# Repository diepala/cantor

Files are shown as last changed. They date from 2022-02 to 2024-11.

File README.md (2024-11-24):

# Cantor Keyboard
The Cantor keyboard is a 42 key diodeless split keyboard, designed with simplicity in mind. It is inspired on the popular [corne](https://github.com/foostan/crkbd), [ferris](https://github.com/pierrechevalier83/ferris) and [sweep](https://github.com/davidphilipbarr/Sweep) keyboards, aiming to provide a more ergonomic (stronger column stagger) corne-like layout with a simple, easy to assemble and cheap design.

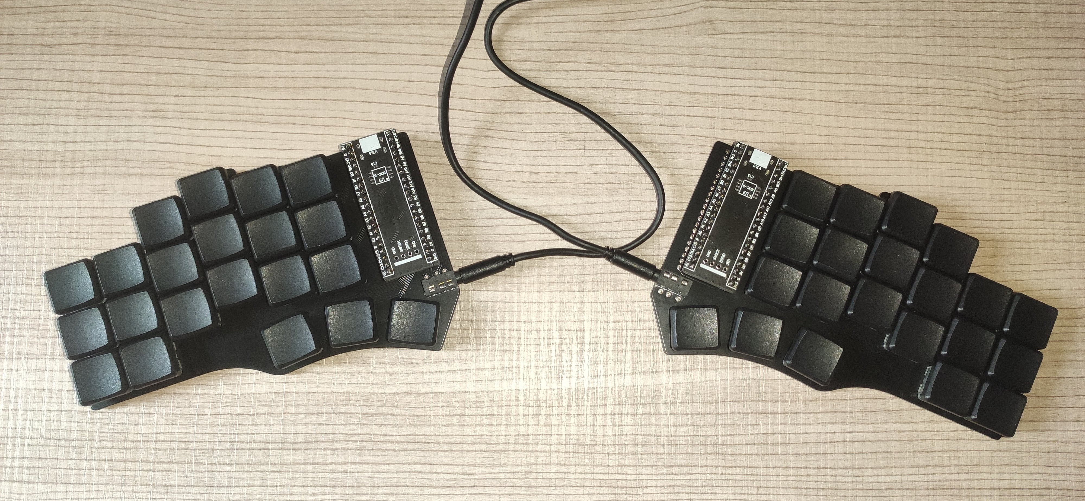
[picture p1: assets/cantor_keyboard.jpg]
Cantor Keyboard


There are two versions of the Cantor:

The **Cantor Classic** uses choc switches with choc spacing. Therefore, only MBK keycaps can be used.

The **Cantor MX** uses either choc V1, choc V2, or MX switches with the slightly larger MX spacing. Keycaps for MX stems can be used. (OEM/SA/XDM/Cherry, etc.) 

Cantor Keyboard

### Why diodeless?

A diodeless design reduces the keyboard assembly time, as the amount of components to solder is significantly reduced.
Moreover, soldering diodes can cause trouble during the keyboard build. Diodes need to be placed in the correct direction, if not, the keys won't work well!
Eliminating diodes will prevent many errors during the assembly process.

## Disclaimers

All the designs and files are provided "AS IS" without any warranty or support.

## Design philosophy

The Cantor is designed with the following goals:

- Comfort
- Powerful
- Low cost
- Simplicity
- Ease of build
- USB-C
- No diodes

The PCB is reversible to reduce manufacturing costs.

## Getting started

Would you like to build this keyboard? Then continue reading!

You can also buy a kit to build the Cantor keyboard from one of the **honorable sponsors**:



<br><br><br><br>
  
### Bill of Materials

To build the keyboard, you will need the following materials:
#### Cantor Classic:
- 2x PCB boards (both are equal since they are reversible)
- 2x STM32F401CC blackpill microcontrollers (they are cheap on aliexpress)
- Pins and sockets for the microcontrollers (blackpill needs 20 pin stripes)
- 42 Choc v1 switches
- 42 MBK keycaps
- Some little rubber feet/bumpers (recommended 6 mm of diameter)
- 2x TRRS jacks (PJ-320A)
- 1x TRRS cable
- 1x USB cable compatible with your computer and the blackpill

#### Cantor MX
- Same as the classic, but switches can be choc v1, choc v2, MX 5 pin, or MX 3pin, and the compatible keycaps for chosen switches. MX 5 pin are preferable to 3 pin because they have more points of contact with the PCB.

- Cantor MX has slots for optional 'Tenting pucks'. They can be [purchased](https://splitkb.com/products/tenting-puck) or [3d printed](https://www.printables.com/model/235433-tenting-puck-for-keyboard-tripod-mount).

### Order the PCB

Download the gerber file from releases, and submit it to your favorite PCB manufacturer. The keyboard designs have been tested with JLCPCB. More details on the ordering process can be found in the [PCB Ordering Guide](doc/pcb_ordering_guide.md).

Note: if you don't want a random tracking number to be printed in the PCB, make sure to select the option 'Remove Order Number' in JLCPCB.

### How to Build

To build the keyboard, you'll also need a soldering iron and some tin. Follow the [build guide](doc/build_guide.md).

### Firmware

The Cantor keyboard uses the QMK firmware, which already supports this keyboard.

To flash the firmware to the microcontroller connect the blackpill to your computer and set it to bootloader mode. To do this the first time:

1. Press and hold the BOOT0 button.
2. Press and release the NRST button.
3. Release the BOOT0 button.

The following times you want to flash the keyboard, it is much simpler thanks to bootmagic. Hold the top left key of the keyboard and plug the microcontroller. If flashing the right part, hold the top right key.

## Feedback

If you have build this keyboard, please fill [this form](https://forms.gle/nfJCsei5hyHbjaHn9) to provide feedback. This will help to improve the keyboard design in future revisions.

Also, you can open an issue reporting any problem or feature request.

## Support

The development of a keyboard takes time and money. If you like this keyboard a want to support me for the work and to develop future revisions of the keyboard, consider donating:

PayPal: 
GitHub: [Here](https://github.com/sponsors/diepala)

### Honorable sponsors

Thank you very much to everyone contributing and/or sponsoring this project. Special thanks to the honorable sponsors:




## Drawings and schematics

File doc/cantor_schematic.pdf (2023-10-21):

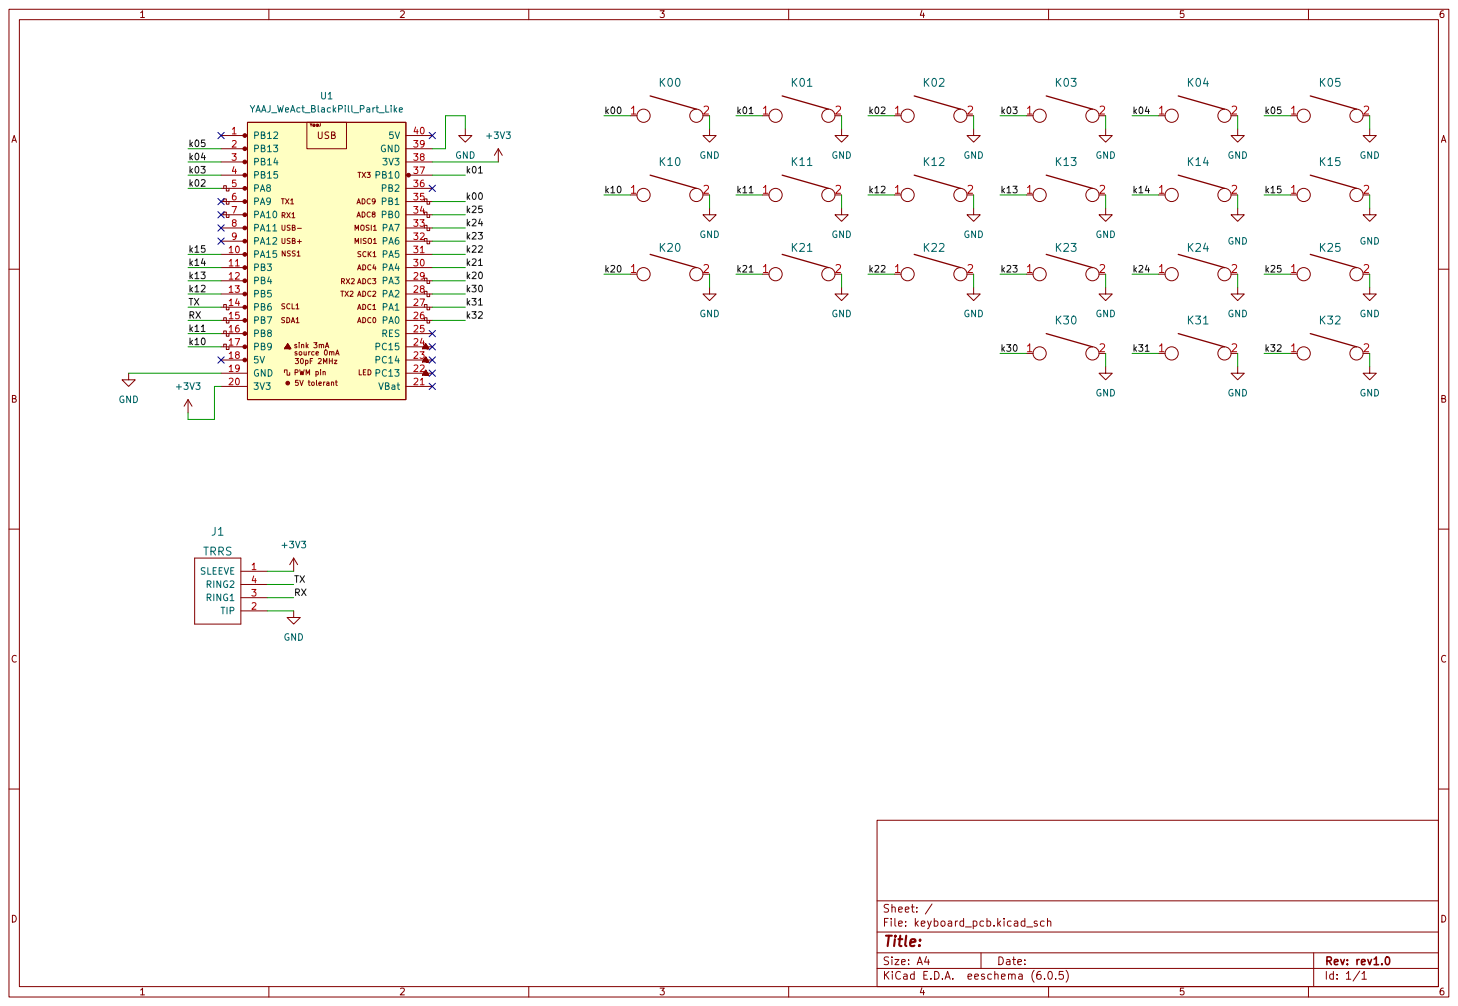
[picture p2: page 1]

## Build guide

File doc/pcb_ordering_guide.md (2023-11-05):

# PCB Ordering Guide.
How to order this board from a PCB vendor - helpful info if it's your first time ordering a PCB.

Most PCB vendors have a similar ordering process. I use [JLCPCB](https://jlcpcb.com/) because they are usually the most cost effective. I've had good luck with [Elecrow](https://www.elecrow.com/) too. [You can find PCB price comparison tools online.](https://pcbshopper.com/) When comparing pricing, the board dimensions are  143mm x 93mm. (Usually anything under 100x100mm is really cheap - so be sure to use the 143x93 dimensions when pricing).

Usually the minimum quantity to order is 5 boards. 

The production files are known as "gerbers", and they are usually uploaded as a `.zip` file. (It's essentially a collection of files for each layer of the board, like holes, graphics, traces etc.) 

In this repo, the gerber file for the Cantor classic and the Cantor MX can be found under [releases](https://github.com/diepala/cantor/releases).

The homepage of JLCPCB has a drag & drop upload. Drag the gerber `.zip` and drop it on the "add gerber file" box.
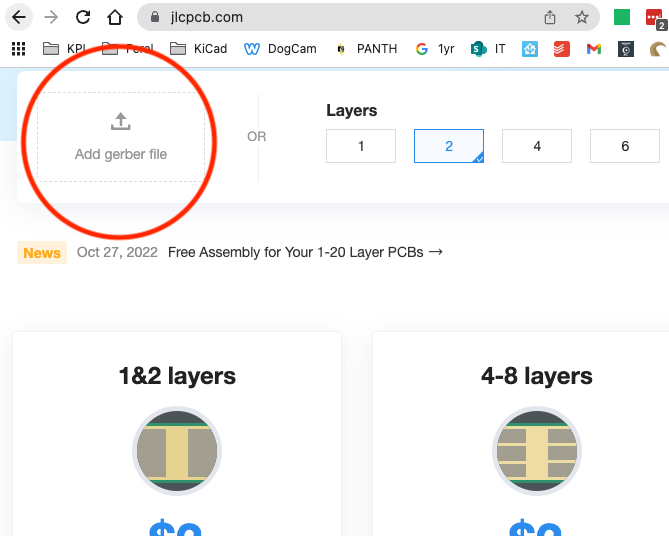
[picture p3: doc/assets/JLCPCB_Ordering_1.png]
JLCPCB Home


While the file is uploading, it will take you to an options screen. Once the board size is detected<sup>1</sup>, the price<sup>3</sup> will update accordingly.
Changing the pcb color<sup>2</sup> may impact production time and price.
Shipping estimates<sup>4</sup> can vary widely, so be sure to check those. (You'll see these options again during checkout).
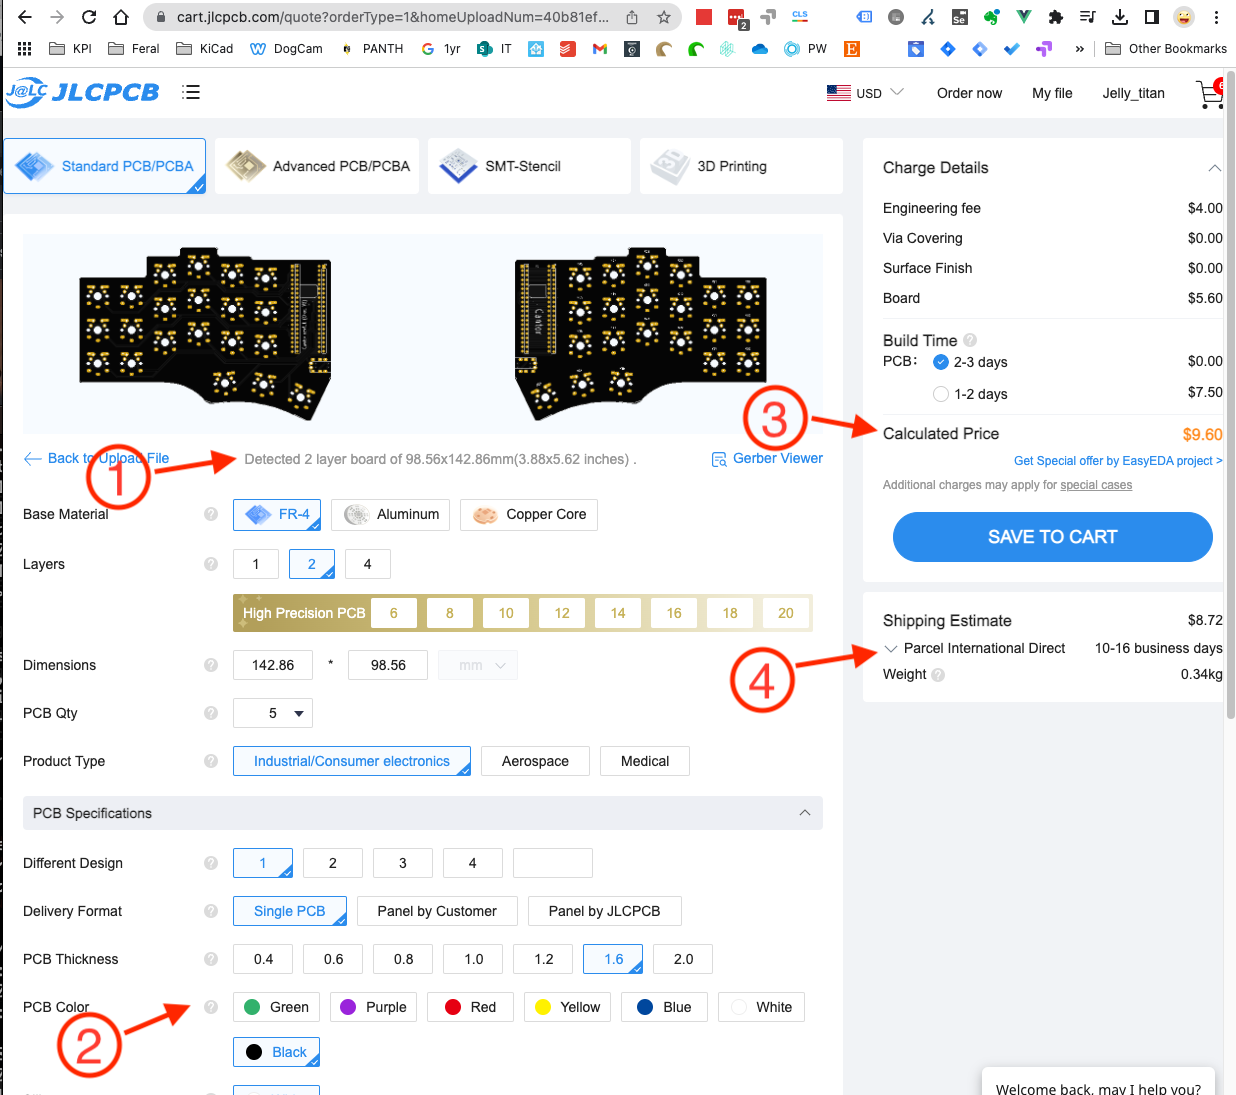
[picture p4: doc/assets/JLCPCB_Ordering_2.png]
JLCPCB Home

It's worth noting, the default pcb surface finish contains Lead. For boards in cases, this is usually not a problem. If you're going to rock a naked board, consider going with "lead free" for a few bucks more.

JLCPCB Home
The remainder of the checkout process is standard ecommerce stuff. After you pay for your order, it will be reviewed before going into production. They will let you know if the file has any issues.

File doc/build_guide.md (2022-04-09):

# Build Guide

1. Solder the pin headers to the blackpill microcontrollers. The microcontroller must be face down, as shown.

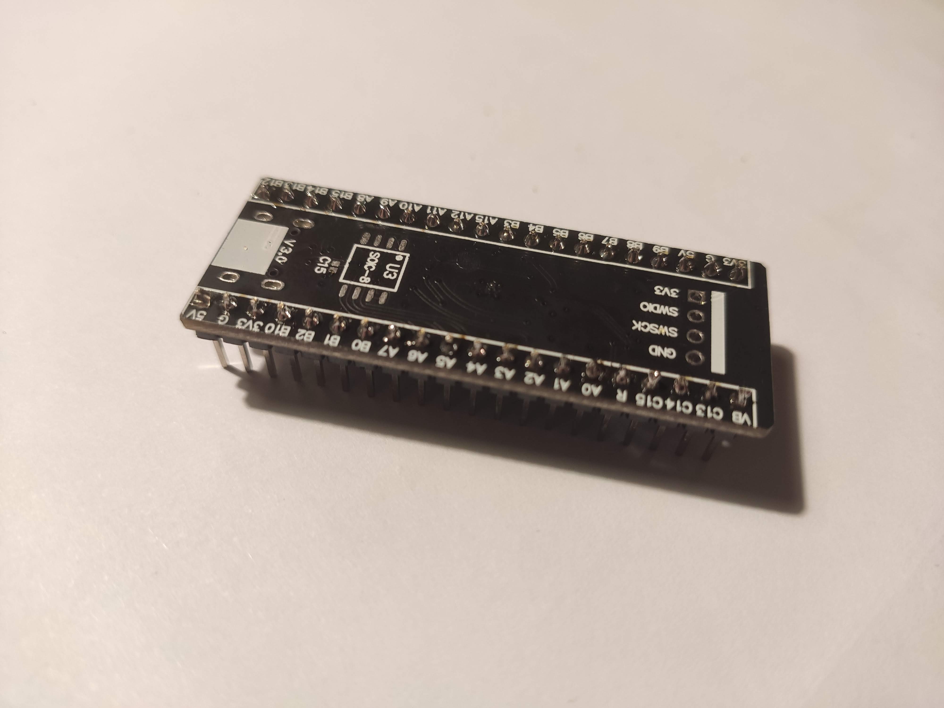
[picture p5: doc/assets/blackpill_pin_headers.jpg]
blackpill with pin headers
   

Optionally, flash the firmware onto the microcontroller to ensure it is not defective.

2. Solder the blackpill sockets and TRRS jacks on both PCBs, as shown. Sockets must be placed on top of the white PCB markings. ALthough using sockets is not strictly necessary, it will make it easier to replace the blackpills in case they die for any reason. Also, make sure you solder the components on different sides of the PCBs, so you end up with a right and left side and not two sides of the same hand.

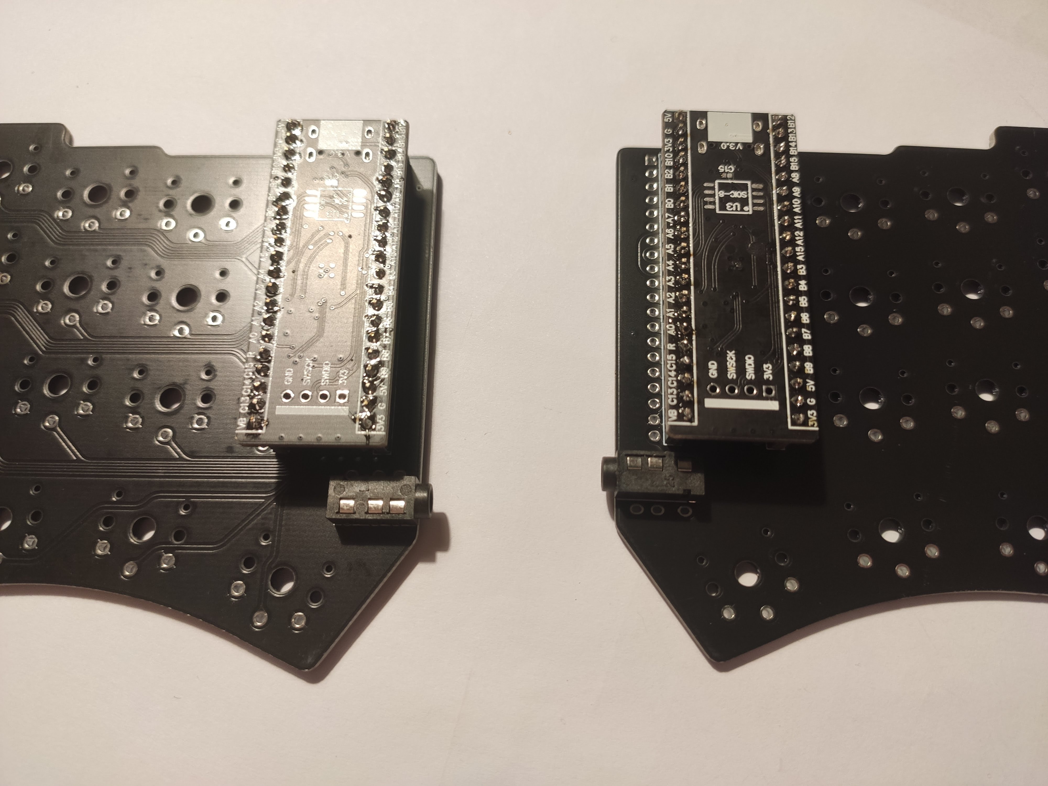
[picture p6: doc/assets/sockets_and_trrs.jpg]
sockets and jack
   

3. Place and solder the switches.

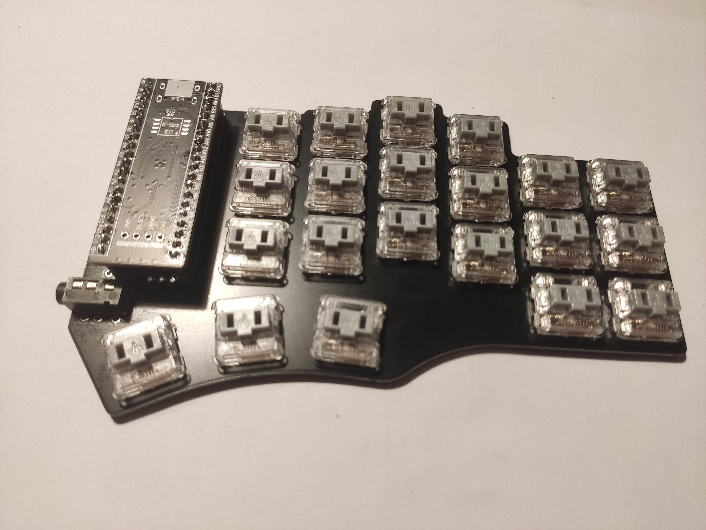
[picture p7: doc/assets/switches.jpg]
switches
   

4. Place the rubber feet on the bottom of the PCB.

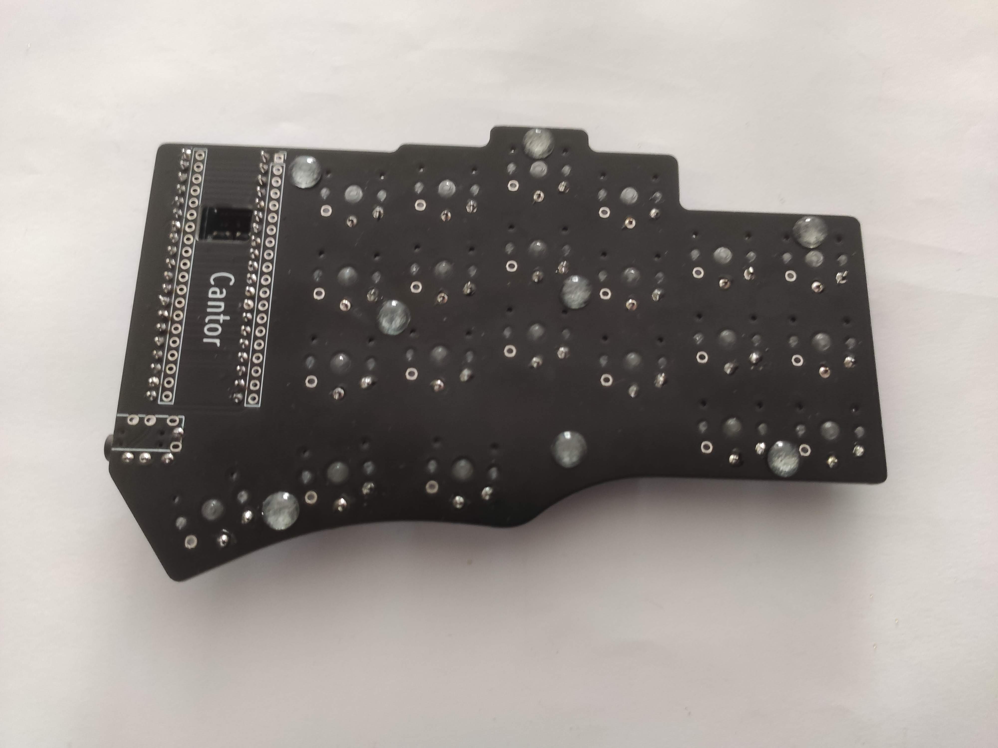
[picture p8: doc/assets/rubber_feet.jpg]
rubber feet
   

5. Place the keycaps on top of the switches. Congrats! Your keyboard is built!

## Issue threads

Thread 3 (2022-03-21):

Add Cantor to splitKbCompare

azzamsa, 2022-03-21:
Hi.

Would you like to  add this to https://github.com/jhelvy/splitKbCompare :)

Would like to compare to other keyboard. Especially [Torn](https://github.com/rtitmuss/torn).

diepala, 2022-03-21:
I will take a look on how to do it when I have time. Meanwhile, you can see how the switches are layed out with kiCad.

azzamsa, 2022-05-23:
Related: https://github.com/jhelvy/splitKbCompare/issues/84

azzamsa, 2022-05-26:
In case anyone want to print the layout (without installing the KiCad):

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

[cantor.pdf](https://github.com/diepala/cantor/files/8779709/cantor.pdf)

l4u, 2022-06-27:
It's available at splitKbCompare now.

azzamsa, 2022-10-24:
> It's available at splitKbCompare now.

Thank you!

Closed 2022-10-24.

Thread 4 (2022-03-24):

Release a 36 key Cantor version

fourstepper, 2022-03-24:
Hi!

A 36 key version of this would be great, are you planning on making this revision?

diepala, 2022-03-25:
Yes, a 36 key version will be the next variant of the Cantor keyboard. I am waiting to having more feedback on the current version first.

stuart-warren, 2022-06-09:
Supporting the nice!nano would be amazing with fewer keys

stuecklberger, 2022-07-20:
FYI: In the meantime someone already created a 36 key version of the Cantor and called it Cantor Remix:

https://github.com/nilokr/cantor-remix

Lumi317, 2022-10-21:
Maybe you would be interested in the Sweep?
https://github.com/davidphilipbarr/Sweep

diepala, 2024-01-05:
Fixed by #25

Closed 2024-01-05.

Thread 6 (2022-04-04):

Create a MX compatible version

twalker, 2022-04-04:
It'd be fantastic to have a version of Cantor that was compatible with MX switches.

MX compatible hot swap sockets would be ideal IMHO, they:
* Are easier to solder than switches themselves
* Allows exploring different switches

twalker, 2022-04-07:
> Have you tested or seen other plateless keyboards with the configuration you propose?

No, I have not. All the MX compatible keyboards I've built (Corne, Kyria, Sofle, etc) used a base and switch plate. They're quite stable with a case, but I imagine they'd be less stable with one. I'm naively imagining a different version of the PCB with the same layout, with non-choc key spacing, along with a switch and base plate designs. If that conflicts with the goals (low cost) of the Cantor, or is impractical, then I totally understand.

diepala, 2022-04-09:
I don't want a switch plate to be mandatory for the build. The MX keyboard won't be a priority for now, but in the future we could make some tests for MX switches.

twalker, 2022-04-09:
@diepala , I look forward to any future possibile explorations of an MX version. As a software engineer, I'm not very skilled with electronics or PCB design, but would happy to be a tester if/when one is needed. Thank you.

ratsclub, 2022-06-24:
Hmm, I just stumbled upon this issue. I can't really build this keyboard for an affordable price because of its switch... There are some MX compatible switches from Red Dragon that are **really** affordable tho. So I'd be happy to try the MX model if it happens to come out!

taurhine, 2022-08-17:
This is a great improvement over corne design. It would be awesome to have it with MX switches!

artsbentley, 2022-09-14:
Yes would love an MX design!

diepala, 2022-09-16:
Seeing that many people would like this version, I will probably make an MX version.

fabikroeger, 2023-02-14:
An MX design would be awesome :+1:

taurhine, 2023-02-18:
or MX Low Profile :heart_eyes: https://www.cherrymx.de/cherry-mx/mx-low-profile/mx-low-profile-red.html

mejobloggs, 2023-02-27:
Redragon AliExpress has two MX compatible low profile switches... Could be a potentially good option!

https://www.aliexpress.com/item/1005004299855522.html

https://www.aliexpress.com/item/1005003606992057.html

However, I have not used either, so I can't verify if they genuinely are MX compatible

albertothedev, 2023-04-04:
Any progress on this? I really like the improvements made over CRKBD but the use of Choc keys is a dealbreaker for me, like I'm sure it is for many others.

JayceFayne, 2023-12-28:
This issue was fixed by #25

Closed 2024-01-05.

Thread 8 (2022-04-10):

LEDs control

wvffle, 2022-04-10:
Is it possible to control the LEDs of the blackpill?

For example I'd love to completely turn the red LEDs off. Or better yet, turn them on when I'm switching layers.

diepala, 2022-04-12:
As far as I know, it is not possible to turn off the red power led, as this is not controlled by the microcontroller.
However, the blackpill has another LED which can be controlled, that is connected to pin C13. It should be possible to configure this LED with QMK, although not sure if it will be very visible due to its position.

kovasap, 2024-10-14:
@wvffle did you ever end up figuring this out?

wvffle, 2024-10-15:
@kovasap no.

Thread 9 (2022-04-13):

Add support for tenting puck

jbarr21, 2022-04-13:
Would it be possible for you to add support for splitkb's [tenting puck](https://splitkb.com/products/tenting-puck)? This would add to the Comfort aspect of the design philosophy while not hurting the Ease of build since it is optional to use.

diepala, 2022-04-18:
Not sure how the tenting puck is mounted, but I'll investigate to see if it can be added.

diepala, 2023-10-24:
And MX version of the keyboard is coming in #25 and it has holes for the tenting puck.

Closed 2024-01-05.

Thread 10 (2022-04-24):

Wireless technically possible?

kekscode, 2022-04-24:
Hello 👋
Long time corne low profile user here. I recently built a corne with ZMK firmware and nice!nano v2 MCU and don’t want to go back having canbles.

I love your pcb design (especially the stagger) and the diodeless approach. Do you think it is possible build a wireless variant of the cantor?

diepala, 2022-04-28:
You would need a blackpill with bluetooth support, but I don't know if that exists.

kekscode, 2022-04-28:
Maybe not (yet?). I‘ll build a cantor this weekend and if it suits me i will do some research. Kudos for the simple design. I am looking at the pcbs right now and i like the KISS approach a lot 👍

azzamsa, 2022-05-16:
@kekscode any update? I love to have the wireless version too.

kekscode, 2022-05-17:
Not really feasible at the moment.

funkycode, 2023-03-07:
I would assume it is with https://mechwild.com/product/pillbug/
Blackpill compatible with BLE and ZMK support

Closed 2022-04-28.

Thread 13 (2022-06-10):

Pin for determining left/right side

dariogoetz, 2022-06-10:
Is there a pin that is grounded for one of the blackpills and not for the other? It would allow determining if an instance of the firmware runs on the left or right half.

I wrote a keyberon-based firmware for the cantor, where I would like to use such a pin. The firmware can be found here: https://github.com/dariogoetz/cantor-firmware-keyberon

diepala, 2022-06-18:
There is no pin grounded on one side but not in the other. I thought of it when designing the keyboard, but that was incompatible (or at least hard to achieve) with a reversible PCB.

dariogoetz, 2022-06-20:
If I understand the pcb correctly, there are two footprints for the MCU. One is used for the left half and the other for the right one. Is it not possible to ground one pin (e.g. A9) only for the one of the two footprints? Am I missing something?

Closed 2022-06-18.

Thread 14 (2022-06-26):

bigger holes for Mill-Max capabilities

itenatic, 2022-06-26:
Tried to insert some 0305 mill-max sockets to make the cantor hotswappable, but they don't fit. the metal rings for the connections make it a little too tight. maybe in the next iteration of the cantor this can be taken into account

maverick1872, 2022-11-11:
@diepala Any idea on when/if hot swap support may be added?

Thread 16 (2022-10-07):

Only USB-C ports

Lumi317, 2022-10-07:
Would it be possible to create a version of the Cantor whose TRRS ports are replaced by USB-C ports?

diepala, 2022-10-16:
Using USB-C ports was an option I thought about when designing the Cantor, but I discarded it because soldering would be more difficult to do by hand. So it is not going to be implemented.

Lumi317, 2022-10-16:
Thank you for taking the time to answer me and thank you very much for creating and sharing the Cantor. <3

Lumi317, 2022-10-17:
I may be wrong, but I seem to have read that some complicated soldering can be done by machines in factories producing PCBs if they are provided with a PCBA file.
Wouldn't this be a way to take advantage of the solidity and universality of USB-C on the Cantor while avoiding the difficulties of manual soldering?

Closed 2022-10-16.

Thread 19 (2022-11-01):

4 keys not working

usizu, 2022-11-01:
Just built this great keyboard, have an issue with 4 keys not working on the right-side though.

They correspond on the default mapping to the `[`, `n`, `m` and `,` keys. So the top-right key, and the bottom left-three (within the main block).

QMK key tester:
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

I suspect the issue is with the controller, not the switches. If I swap the controller with the one on the other side, then the same mirror-positions stop working on that side.

I'm new to keyboards and hope to get some help in troubleshooting this.

1) Could it be something simple like one or more improperly soldered pins on the controller?
2) Is it easy to determine which pins govern these keys, so I can adjust the soldering on those pins?
3) What would be sufficient criteria to determine if I should just buy a new blackpill?

Thanks for any help.

diepala, 2022-11-19:
Hi, probably you will have to replace blackpill, but you can check if the balckpill is working by short-circuiting to ground, with a wire, the pins corresponding to the non-working keys. Connecting a pin to ground is equivalent to pressing the associated key, so you should see as if that key is pressed in the computer.

Your keys correspond to pins B1, A6, A7 and B0.

usizu, 2022-12-10:
Hi, thanks for this message.
I finally got around to trying this, and indeed the pins from A6 up to B1 don't register a keypress whereas the others do, so this seems to affirm that its this blackpill unit that is faulty, thanks for the help

------- Original Message -------
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

Closed 2023-02-23.

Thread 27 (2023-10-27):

Board always in Bootloader-mode

noggynoggy, 2023-10-27:
I am sorry if this is not the right place to ask this, but I don't know where else to ask:

One half of my Cantor doesn't type. The Blackpill seems to be in bootloader mode constantly, even after flashing. After I disconnect the cable, and replug, I can instantly flash with `qmk`, without having to press the `BOOT0 NRST nrst boot0` combo.

I had to resolder some parts on that side (I'm bad at this), so I suspect it's because of bad soldering somewhere. What pins (or switches?) should I take a look at? What could cause the Blackpill to be in Bootloader mode all the time? I tried to read the Documentation of the board, but I'm afraid all of it went right over my head...

Thanks in advance!

Closed 2023-11-10.

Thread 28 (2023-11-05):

MCU Orientation

fla-t, 2023-11-05:
I have ordered a cantor PCB, and just waiting for the switches to be built. I noticed that you have heavily said that the controller must be face up.

But, in the PCB I noticed that there are 2 Pin arrays, It seems like they are mirror opposite of each other. Meaning I don't need to face down the PCB if I choose the one that has a square white mask around it.

My question is am I right?

Sorry if it doesn't feel like an issue, because I have no other way to ask this.

diepala, 2023-11-05:
As it was originally designed, the microcontroller should be soldered on the white mask face down as shown:

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

But you are right in that it can be soldered face up on the other row of holes.

fla-t, 2023-11-06:
Thank you so much, I think I should update the docs a little bit.

Closed 2023-11-05.

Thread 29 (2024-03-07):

The MX release contains two gerber files.

The-Abe, 2024-03-07:
The zip release for the MX version contains the gerber files and another zip containing gerber files.

This causes jlcpcb to reject the board during review.

Blubberland, 2024-04-08:
Cannot confirm.
The second layout was automatically stripped away when I added it to the cart. (I was wasn't sure how it would be handled during the order process, so I just waited until delivery).
Package was delivered today and contains 5 pieces (not 10).
Would have been nice to know beforehand. I would have ordered an even number. Could be added to the [ordering guide](doc/pcb_ordering_guide.md).

simonvanbernem, 2024-04-26:
I encountered the same thing.

jlcpcb emailed me, asking what to do about the internal zip file, and I instructed them to ignore it (which I hope was the right thing, as it claims to be v1.61 dated 10-24-2023, while the release zip is v1.6 from 11-05-2023 (later date, but earlier version??).

It would be great if the internal zip file could be deleted, so that newbies like me don't get surprised by this.

yantongl, 2024-05-16:
I ran into the same problem.

If you unzip the `gerber-cantor-mx-rev1.6.zip` file, you will see it contains another zip file `cantor_mx_v1.61_10-24-2023.zip`. I am going to tell them to ignore the internal zip file as @simonvanbernem said above.

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

simonvanbernem, 2025-04-24:
> If you unzip the `gerber-cantor-mx-rev1.6.zip` file, you will see it contains another zip file `cantor_mx_v1.61_10-24-2023.zip`. I am going to tell Jlcpcb to ignore the internal zip file as [@simonvanbernem](https://github.com/simonvanbernem) said above.

For the record: This turned out to be the correct choice. Everything worked out in my case.

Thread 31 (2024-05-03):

Request for Adding RGB Lighting to Cantor Keyboard PCB for Enhanced Functionality

ripertio, 2024-05-03:
As a user who built the Cantor Keyboard as my first split keyboard, I have thoroughly enjoyed the experience, especially appreciating the simplicity of the build process and the clear assembly guide provided. Despite being new to the splitboard game, I found the Cantor Keyboard to be user-friendly and intuitive.

One feature that I believe would greatly enhance the Cantor Keyboard is the addition of RGB lighting to the PCB For a beginner like me, having RGB lighting on the Cantor Keyboard would provide visual cues for different functions, such as indicating which layer is currently active.

I believe that integrating RGB lighting into the Cantor Keyboard PCB would not only elevate its overall appeal but also provide practical benefits for users, especially those new to split keyboards. Thank you for your attention to this request.

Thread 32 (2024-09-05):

Keyboard doesn't work until I reconnect it

arielarmijo, 2024-09-05:
The keyboard works fine, I love it, but after I turn on the PC, the  keyboard won't work until I disconnect and re-connect it again.

I have build it with the blackpill [STM32F401CCU6 3.0](https://es.aliexpress.com/item/4001049840288.html). In my config.h file i have this code:
```
#pragma once

#define MASTER_LEFT
#define USB_WAIT_FOR_ENUMERATION
#define LAYER_STATE_8BIT
```

Is there any specific settings I should use to fix this issue?

Thanks for design this awsome keyboard. Here is my [build in reddit].(https://www.reddit.com/r/ErgoMechKeyboards/comments/yaotqf/my_cantor_build/).

dimipage, 2024-10-12:
Do you use a usb hub by any chance? I had the same issue and switching the hub or connecting directly to pc helped.

arielarmijo, 2024-11-11:
> Do you use a usb hub by any chance? I had the same issue and switching the hub or connecting directly to pc helped.

Thanks @dimipage for you commnet. I connect it directly to the computer. What version of QMK did you use?

dimipage, 2024-11-12:
> > Do you use a usb hub by any chance? I had the same issue and switching the hub or connecting directly to pc helped.
>
> Thanks @dimipage for you commnet. I connect it directly to the computer. What version of QMK did you use?

I've downloaded the latest repo, main branch

mraspaud, 2025-03-01:
I have the same issue, and same controller. I tried a few things, but the problem is still there...

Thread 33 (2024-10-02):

Almost nothing works because of wrong Micro Controller?

xbello, 2024-10-02:
I bought and soldered all the pieces, was able to flash the firmware, and all looked good. But almost no key worked, and the ones that triggered a key press was doing it bad (on repeat, multiple chars, etc).

I tested the soldering with a tester, and noticed that a lot of switches were only conected to the GND. The signal pin was connected to an unconnected hole under the MC, so no surprise they can't trigger a keypress.

On closer inspection, I noticed that my MC is so wide that it had to be soldered *to the outer pins only*, leaving the inner holes disconnected. Your image for the "build guide" where it shows the rubber feet clearly show that the MC uses one of the inner lines of holes and one of the outer lines of holes!

This is what I bought, claims to be a STM32F401CC: https://es.aliexpress.com/item/1005005777418296.html

Finally, the question: *what do I have to search for to ensure the MC has the correct dimensions*?

Thanks!

dimipage, 2024-10-12:
I have a few STM32 dev boards, and can confirm that there is a bigger footprint on one of them, which does not fit on Cantor. The link you have provided shows the exact dev board that is required, but picture in customers review section displays a bigger one. I assume that the seller does not care about the sizes and have sent you the one which does not fit.
For example, I have mistakenly ordered from this link https://www.aliexpress.com/item/1005006127461676.html but the seller actually displayed the sizes, so it was all on me.

And to answer your question, these are the rough dimensions I got from the repo.
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
So, look for 18mm version.

Have a good day.

Closed 2024-11-24.

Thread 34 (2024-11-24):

is blackpill STM32F411 compatible

SppamLite, 2024-11-24:
I'm trying to find blackpill STM32F401CC on aliexpress, but it seems discontinued.

I'm wondering if the WeAct BlackPill STM32F411CEU6 would be compatible, or is there better option out there?

Thanks!

diepala, 2024-11-24:
It is a more powerful chip, and it should be compatible.

SppamLite, 2024-11-24:
Thanks for the quick reply!

Closed 2024-11-24.

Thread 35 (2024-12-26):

Problem with bootloader and possible solution

mraspaud, 2024-12-26:
I recently built the mx version of this keyboard, and I really like it, so first of all, thanks a lot for creating this project!

Now that I'm tweaking my layout with qmk, I realise that I have a lot of problems getting the controller in bootloader mode, either with the boot0 and nrst buttons or with qmk's bootmagic, in that it works once in twenty times maybe.

I used the blackpill stm32f401ccu6 v3 from ali express, which seems to be working fine otherwise.

I googled the problem and realised that I'm not the only one with it. In particular [this thread](https://www.stm32duino.com/viewtopic.php?t=1680) seems to indicate it is known and has a simple solution of connecting pin A10 to ground (explanation on why in the last post of that thread).

Hence, I soldered a wire between the ground and A10 and can confirm that setting the microcontroller in bootloader mode now works reliably every time, either with the buttons or with bootmagic.

So my request here would be if it would be possible to patch the pcb files to add a trace between ground and a10 to avoid the problem in the future altogether?

Some comments indicate that noise on A10 might be due to static, and indeed I have my keyboard on a plastic surface, so maybe I'm more prone to the problem that others, but I think it would be quite nice with this preventive measure.

Here is a picture of my quickfix:
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

Thanks again for the project!
Martin

svc-user, 2025-04-25:
I now have my own Cantor MX in hand, witht he Blackpill STM32F401, and upon further reading the datasheet A10 specifically does not include an internal pull-up/pull-down resistor. The QMK website says you should use a pull-up at 22k, but I am able to get into DFU mode by shorting to ground. However I'm not sure that's the best approach as the key k25, is using pin A10. More test to be done :)

mraspaud, 2025-04-28:
@svc-user Sorry I missed you messages earlier!
Indeed, a10 is not connected to anything (ie not track on the board connects to in), hence my suggestion to add a track to ground for it...

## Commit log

2022-04-09 Add note to build guide to flash blackpill before soldering (#5)
2023-10-21 Add schematic document (#20)
    Add the schematic PDF so people that are debugging their device don't need to download kicad.
2023-11-05 Cantor mx (#25)
    * Swapped in Choc V2 switches, updated routing and outline
    Removed redundant groundplane routing
    Created double sided chocV2 footprint based on the kbd repo
    * Updated readme.
    * Added images
    * Added images to Readme, fixed formatting
    * Added gerbers
    * Routing and edgecut cleanup, DRC error fixes
    * Fixed drill layer misalingment and regenerated Gerbers
    * Updated readme with pcb ordering instructions
    * Added branding and rebuilt gerbers
    * Moved Blackpill l closer to top edge to accomidate wide-lipped usb-c
    * Revised footprint for better Cherry MX 3-pin support
    Added teardrops
    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
    [Cantor_MX-B_Cu.gbl, Cantor_MX-B_Mask.gbs, Cantor_MX-B_Paste.gbp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]
